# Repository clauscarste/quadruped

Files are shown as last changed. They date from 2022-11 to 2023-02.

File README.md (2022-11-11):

# high performance quadruped with fully actuated spine and brushless motors 
Project is part of my bachelor's thesis at the technical university Munich

Repostory inclues: 
- code running on raspbery pi (python3)
  - matlab scripts used to help create python code
- configuration of Odrive 
- STL files o 3D print and CNC/Laser cut 
- schematics for electronics 
overview_real
(white = FDM:PETG, Black = FDM:nylon-carbonfiber and Pulley Belt, Red = Aluminium 3mm, Blue = Fasteners, Orange = Siliconerubber)

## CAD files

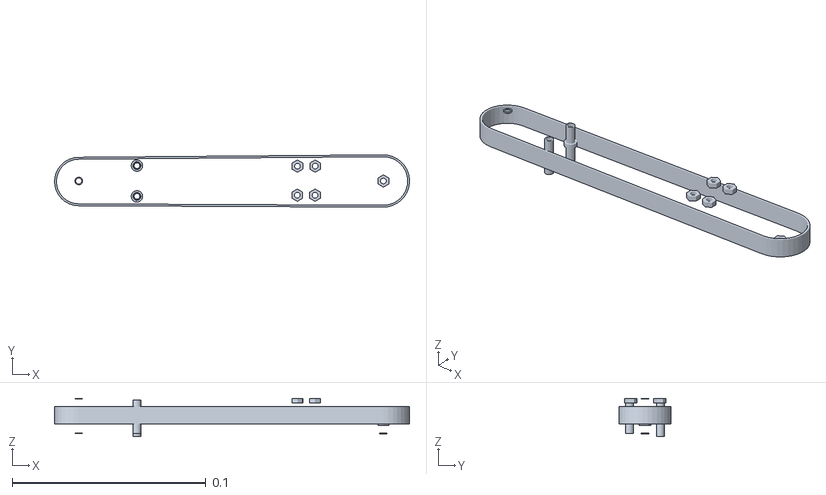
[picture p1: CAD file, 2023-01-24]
control and simulation/simulation_files/simulation_test/full_quadruped_simulation_pos_control/meshes/upper_leg_belt8.stl
0.183 x 0.027 x 0.0197

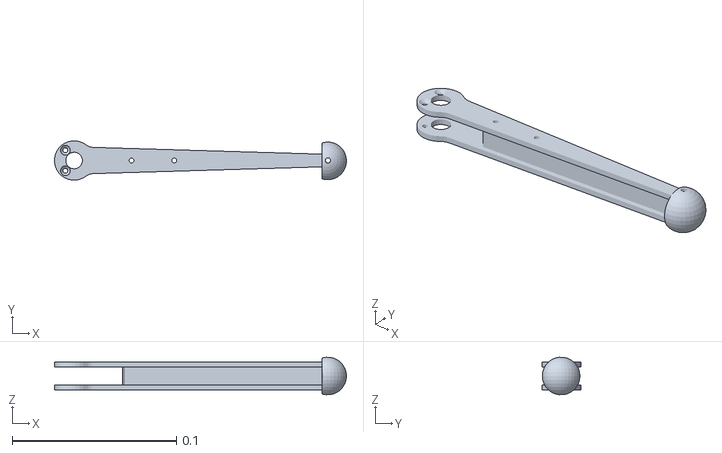
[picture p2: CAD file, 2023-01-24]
control and simulation/simulation_files/simulation_test/leg_only_simplided copy/meshes2/lower_leg7.stl
0.178 x 0.0239 x 0.0229

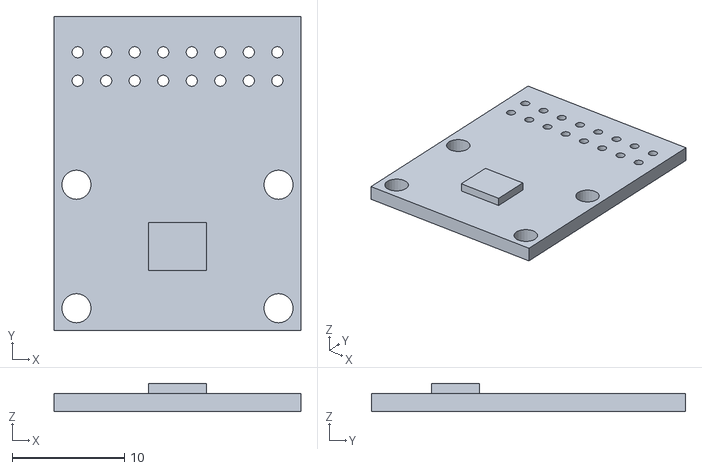
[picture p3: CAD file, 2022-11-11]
stl_files/Gearbox/g10.stl
22.0 x 28.0 x 2.51

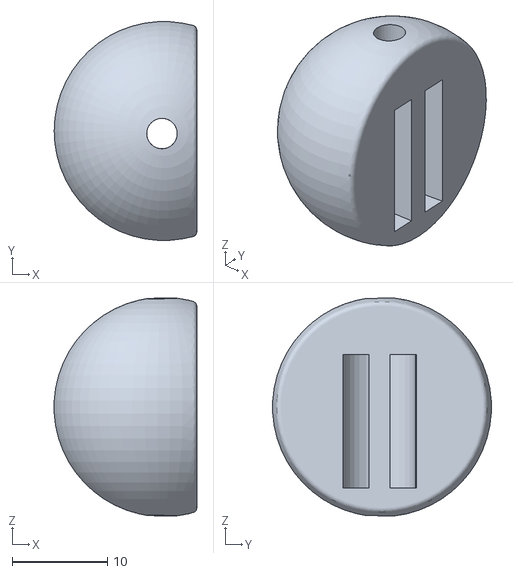
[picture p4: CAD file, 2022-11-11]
stl_files/Leg/l11.stl
15.0 x 22.9 x 22.9

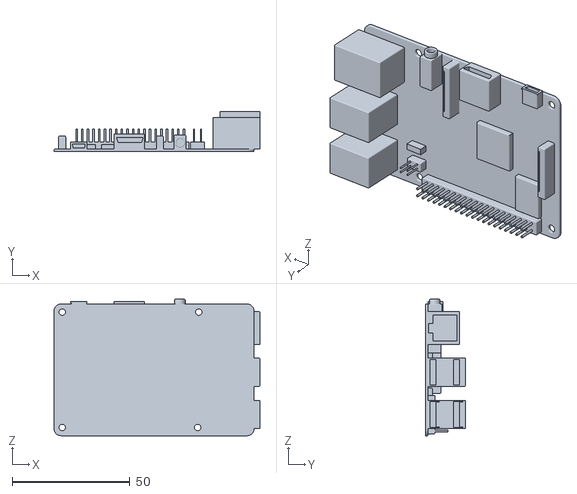
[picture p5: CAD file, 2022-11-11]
stl_files/Main Body/m14.stl
87.5 x 17.0 x 58.0

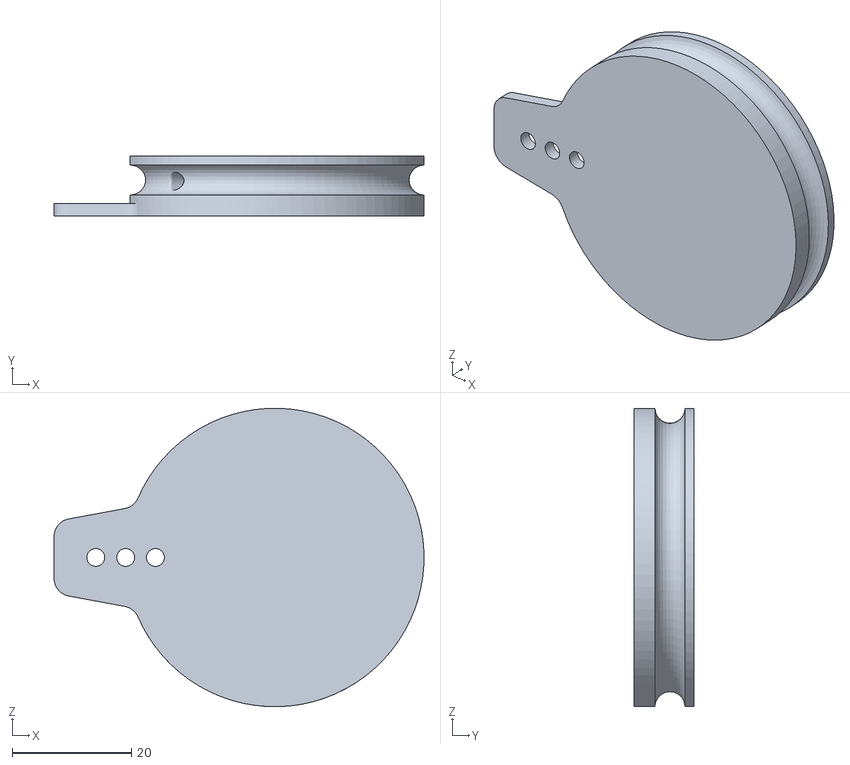
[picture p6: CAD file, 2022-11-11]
stl_files/Spine/s3.stl
62.0 x 10.0 x 50.0

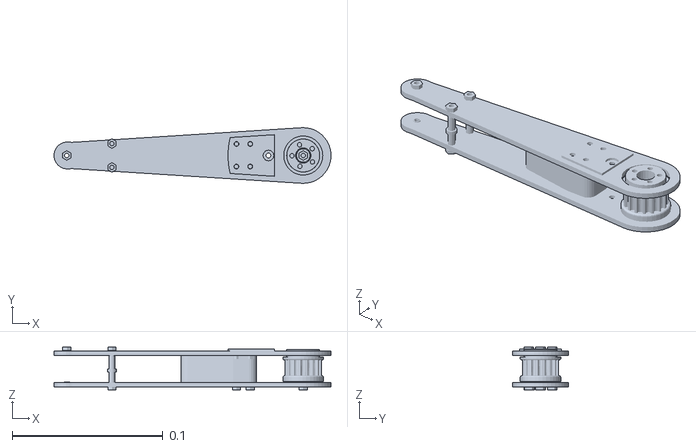
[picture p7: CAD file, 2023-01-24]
control and simulation/simulation_files/simulation_test/full_quadruped_simulation_pos_control/meshes/upper_leg8.stl
0.184 x 0.0369 x 0.0285

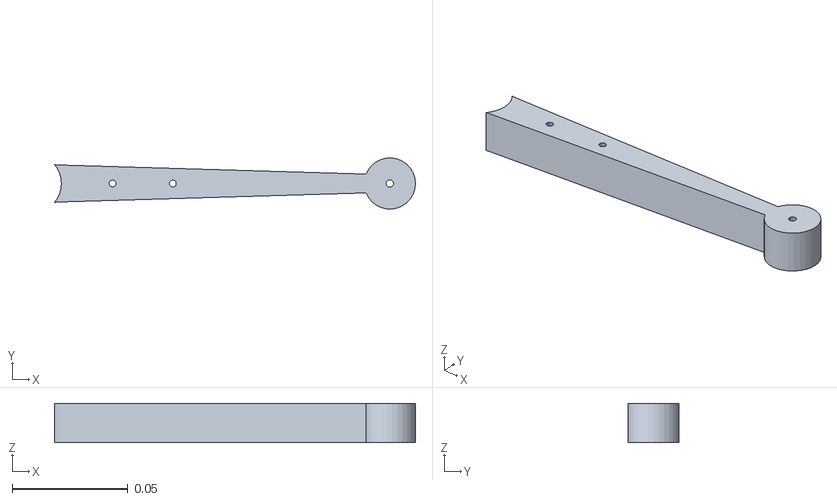
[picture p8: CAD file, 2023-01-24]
control and simulation/simulation_files/simulation_test/leg_only_simplided copy/meshes2/lower_leg.stl
0.156 x 0.0221 x 0.017

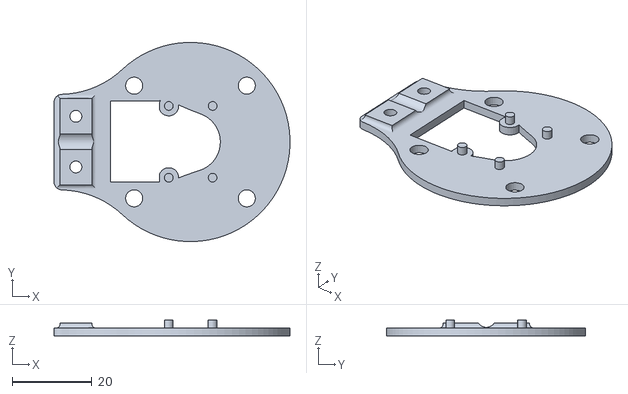
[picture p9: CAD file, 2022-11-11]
stl_files/Gearbox/g11.stl
59.2 x 50.0 x 4.00

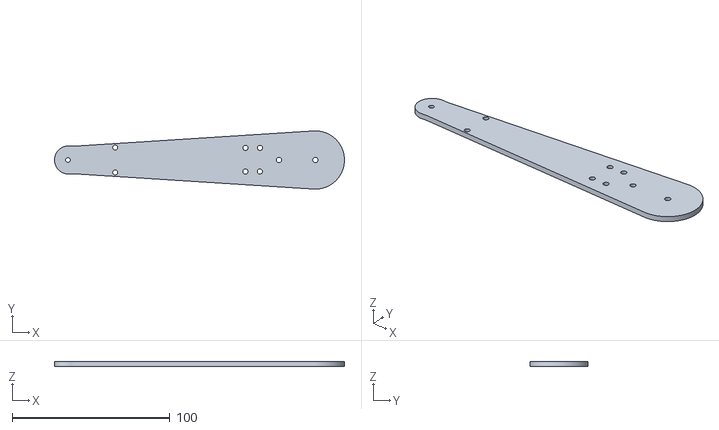
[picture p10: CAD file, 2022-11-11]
stl_files/Leg/l4.stl
184.1 x 37.0 x 3.00

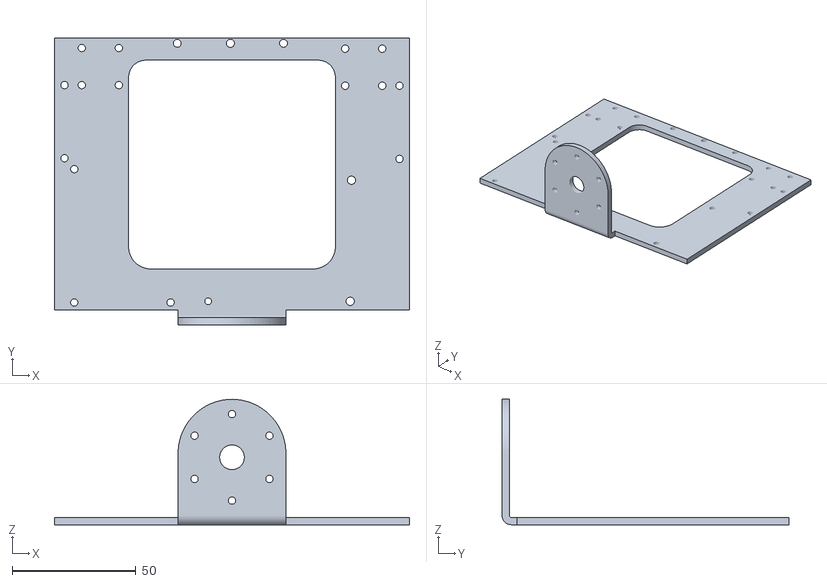
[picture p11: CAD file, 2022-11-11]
stl_files/Main Body/m4.stl
143.7 x 116.2 x 50.8

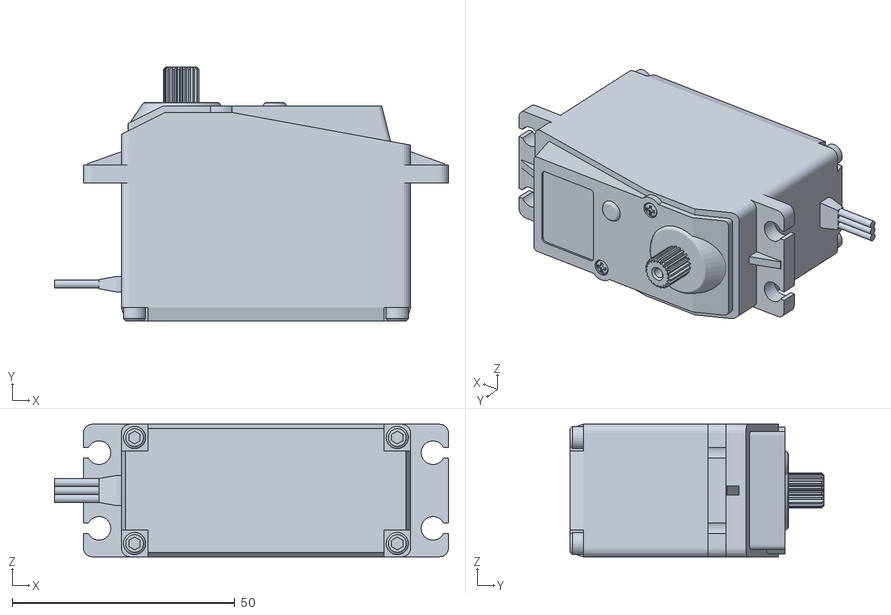
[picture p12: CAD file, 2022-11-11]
stl_files/Spine/s5.stl
88.5 x 57.0 x 29.8

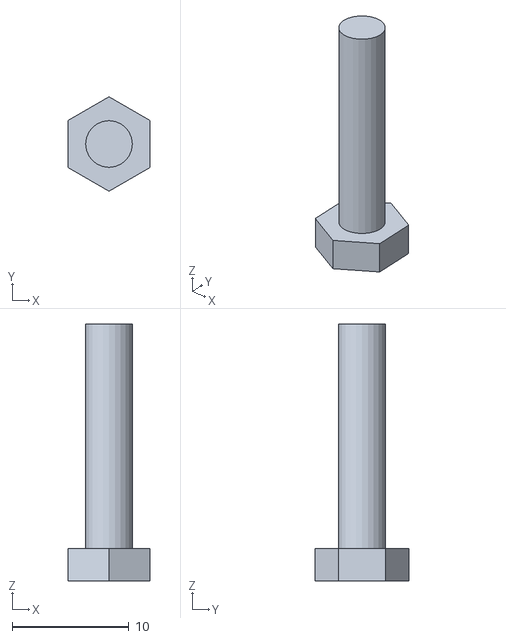
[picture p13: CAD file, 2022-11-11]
stl_files/Gearbox/g9.stl
7.00 x 8.08 x 22.0

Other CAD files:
control and simulation/simulation_files/full_quadruped_simulation_servo/meshes/back_alu_1.stl
control and simulation/simulation_files/full_quadruped_simulation_servo/meshes/back_alu_2.stl
control and simulation/simulation_files/full_quadruped_simulation_servo/meshes/battery.stl
control and simulation/simulation_files/full_quadruped_simulation_servo/meshes/encoder.stl
control and simulation/simulation_files/full_quadruped_simulation_servo/meshes/front_alu_1.stl
control and simulation/simulation_files/full_quadruped_simulation_servo/meshes/front_alu_3.stl
control and simulation/simulation_files/full_quadruped_simulation_servo/meshes/gearbox1_spacer.stl
control and simulation/simulation_files/full_quadruped_simulation_servo/meshes/spacer_spine.stl
control and simulation/simulation_files/full_quadruped_simulation_servo/meshes/upper_leg.stl
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

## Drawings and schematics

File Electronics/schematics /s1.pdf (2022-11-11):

## PWMServo Driver PCA9685

## V+ 16 VCC 17 SDA 18 SCL 19 OE 20 GND 21

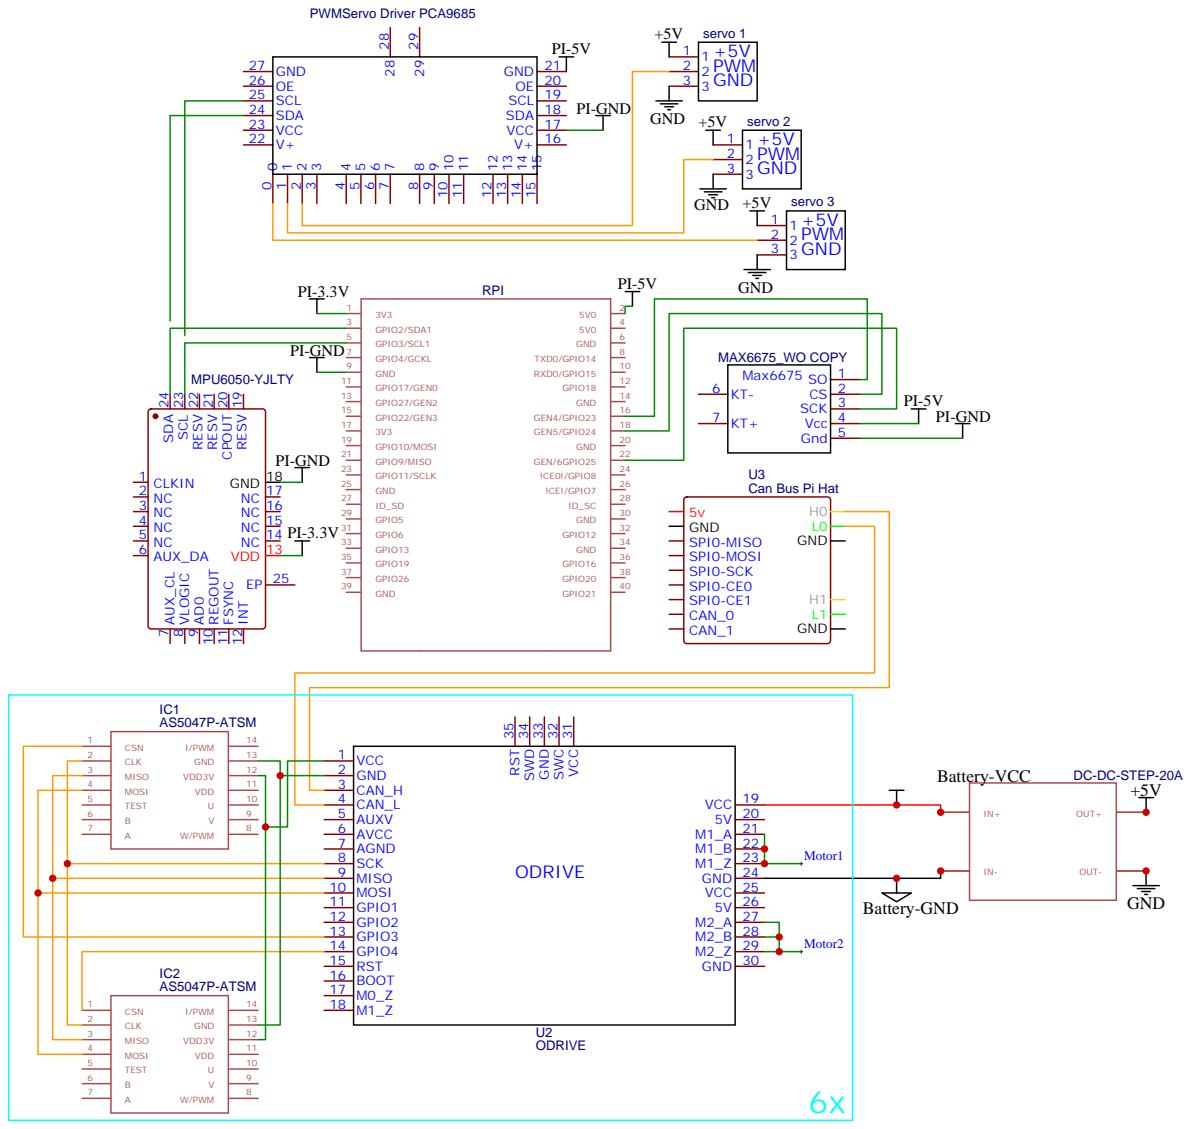
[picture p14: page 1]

V+ 22 VCC 23 SDA 24 SCL 25 OE 26 GND 27

VDD 13 NC 14 NC 15 NC 16 NC 17 GND 18 RESV 19 CPOUT 20

Can Bus Pi Hat

ODRIVEVCC 31 SWC 32 GND ³³ SWD ³⁴ RST 35

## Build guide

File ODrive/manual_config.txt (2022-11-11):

**Configuring the Odrives is best done on a PC running Linux (Ubuntu) using a USB cable that has a ferrite ring to ensure good conection. Blocks of commands can be all sent together. After each block it is advised to restart the Odrive. **

**Config:**
***step 1 run all the commands below in the Odrivetool***

odrv0.config.dc_bus_undervoltage_trip_level = 15
odrv0.config.dc_bus_overvoltage_trip_level = 21.2
odrv0.config.dc_max_positive_current = 140
odrv0.config.dc_max_negative_current = -12
odrv0.axis0.motor.config.current_lim = 50
odrv0.axis0.motor.config.motor_type = 0
odrv0.axis0.motor.config.pole_pairs = 20
odrv0.axis0.motor.config.torque_constant = 8.27 / 130
odrv0.axis0.encoder.config.abs_spi_cs_gpio_pin = ********must be set to 7 or 8***********
odrv0.axis0.encoder.config.mode = ENCODER_MODE_SPI_ABS_AMS
odrv0.axis0.encoder.config.cpr = 2**14
odrv0.axis0.controller.config.pos_gain = 50
odrv0.axis0.controller.config.vel_gain = 0.5
odrv0.axis0.controller.config.vel_integrator_gain = 0.0
odrv0.axis0.config.can_node_id = ********must be set according to the defined axis naming***********
odrv0.axis0.controller.config.vel_limit = 20
odrv0.axis0.config.can_heartbeat_rate_ms = 500
odrv0.save_configuration()

***step 2: Initial motor inductance and encoder offset calibration. Run all the commands below - the motor should spin in two directions slowly by half a rotation***

odrv0.axis0.requested_state = AXIS_STATE_FULL_CALIBRATION_SEQUENCE
odrv0.axis0.motor.config.pre_calibrated = True
odrv0.axis0.encoder.config.pre_calibrated = True
odrv0.save_configuration()

***step 3: Filter - Run all commands belwo***
odrv0.axis0.controller.config.input_mode = INPUT_MODE_POS_FILTER
odrv0.axis0.controller.config.input_filter_bandwidth = 20
odrv0.save_configuration()

**Helpful commands for testing: and debugging**
**Debug:**
dump_errors(odrv0)
odrv0.clear_errors()
odrv0..axis0.clear_errors()
odrv0.vbus_voltage
odrv0.axis0.motor.current_control.Iq_measured
odrv0.save_configuration()

**Testing movement**
odrv0.axis0.motor.config.current_lim = 1
odrv0.axis0.requested_state = AXIS_STATE_CLOSED_LOOP_CONTROL
odrv0.axis0.controller.input_pos = 1
odrv0.axis0.requested_state = AXIS_STATE_IDLE

***run all commands from above again but replace axis0 with axis1***

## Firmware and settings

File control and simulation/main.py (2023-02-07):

#general imports
from __future__ import division
import time
import numpy as np
import kinematics_legs
import walking
#import kinematics_spine                #not implemented in simulation and not used in real word currently
import jumping

import datetime as dt
import matplotlib.pyplot as plt
import matplotlib.animation as animation

#############################  uncomment real world and simulation here and in the kinematics_legs.py  ################
#for real world testing
"""
from realworld import temprature_readout
from realworld import can_comunication
can_comunication.dictionary()
"""
#for simulation
from simulation import temprature_readout
from simulation import can_comunication

#############################  uncomment real world and simulation here and in the kinematics_legs.py  ################


# Config File Import
import configparser
#Config file reading is done in main loop

def get_measured_force():
    return can_comunication.measured_force

def main_loop():
    #config file reading
    config_obj = configparser.ConfigParser()
    config_obj.read("/Users/claus/pyc/quadruped/control and simulation/configfile.ini")

    save_operation_limits = config_obj["save_operation_limits"]
    servo_config = config_obj["servo_config"]
    motor_config = config_obj["motor_config"]
    can_retry_amount = config_obj["can_retry_amount"]

    # Temprature and Voltage limits of motors and battery
    save_operation = True
    temprature_limit = float(save_operation_limits["temprature_limit"])
    battery_voltage_lower_limit = float(save_operation_limits["battery_voltage_lower_limit"])
    battery_voltage_upper_limit = float(save_operation_limits["battery_voltage_upper_limit"])

    # servo_initial_angles and ofset (negative defined)
    servo_1_inital_angle = float(servo_config["servo_1_inital_angle"])
    servo_2_inital_angle = float(servo_config["servo_2_inital_angle"])
    servo_3_inital_angle = float(servo_config["servo_3_inital_angle"])
    servo_ofset = list(map(float, (servo_config["servo_ofset"]).split()))
    distance_center_of_spine_to_rope_m = float(servo_config["distance_center_of_spine_to_rope_m"])
    spine_length = float(servo_config["spine_length"])
    max_angle = float(servo_config["max_angle"])
    pully_radius = float(servo_config["pully_radius"])
    norma_rope_length = float(servo_config["norma_rope_length"])

    # Motor parameters
    motor_inital_x = list(map(float, (motor_config["motor_inital_x"]).split()))
    motor_inital_y = list(map(float, (motor_config["motor_inital_y"]).split()))
    motor_inital_z = list(map(float, (motor_config["motor_inital_z"]).split()))
    ofset = list(map(float, (motor_config["ofset"]).split()))
    limit = list(map(float, (motor_config["limit"]).split()))
    invert_axis = (list(map(int, (motor_config["invert_axis"]).split())))
    leg_parameters = list(map(float, (motor_config["leg_parameters"]).split()))
    can_comunication.kpkv = list(map(float, (motor_config["kpkv"]).split()))
    robot_length = float(motor_config["robot_length"])
    robot_with = float(motor_config["robot_with"])
    contact_f = float(motor_config["contact_f"])

    leg_config = float(motor_config["leg_config"])
    step_lentgh = float(motor_config["step_lentgh"])
    stance_max_height = float(motor_config["stance_max_height"])
    flight_max_heigth = float(motor_config["flight_max_heigth"])
    neutral_height = float(motor_config["neutral_height"])
    speed_stance = int(motor_config["speed_stance"])
    speed_flight = int(motor_config["speed_flight"])
    acceleration_stance = float(motor_config["acceleration_stance"])
    deceleration_stance = float(motor_config["deceleration_stance"])
    acceleration_flight = float(motor_config["acceleration_flight"])
    deceleration_flight = float(motor_config["deceleration_flight"])

    # Number of times to retry after failing to send message over can bus
    closed_loop_attempt = int(can_retry_amount["closed_loop_attempt"])
    ### # end of config file reading


    #fixed values for now
    xm = 0
    ym = 0
    zm = 0
    yaw = 0
    pich= 0
    roll= 0

    #### Inital steps after startup####
    # Spine setup to zero position
    #kinematics_spine.inverse_kinematics_spine(0,0,distance_center_of_spine_to_rope_m,servo_ofset,max_angle,spine_length,pully_radius,norma_rope_length)

    # test that can works and encoders give good reading - also fill in libary
    for i in [0, 1, 2, 3, 4, 5, 6, 7, 8, 9, 10, 11,0, 1, 2, 3, 4, 5, 6, 7, 8, 9, 10, 11]:
        can_comunication.get_encoder_estimate(i)
    for i in [0, 1, 2, 3, 4, 5, 6, 7, 8, 9, 10, 11]:
        print(can_comunication.get_encoder_estimate(i), "     this is ", i)

    # set motor closed loop
    can_comunication.setall_closed(closed_loop_attempt)

    #Set motor to inital positon
    upper = -0.25
    land = -0.25
    lower = -0.25
    delay = 0.1
    jumping.jump(land, upper, lower, delay, leg_parameters, ofset, limit, invert_axis, leg_config, yaw, pich, roll, xm,
                 ym, zm, robot_length, robot_with)

    ###### Main loop based on keyboard input ######
    while save_operation == True:
         # chck for save operation (temprature and battery voltage)
        if can_comunication.is_bus_voltage_in_limit(battery_voltage_lower_limit,battery_voltage_upper_limit) is False or temprature_readout.is_temp_in_limit(temprature_limit) is False:
            save_operation = False
            can_comunication.setall_idle()
            print("not save")
        ##temporary override to always start walking
        #can_comunication.currently_walking = True
        if can_comunication.walk == True and can_comunication.currently_walking == False:
            can_comunication.currently_walking = True
            can_comunication.walk = False
        if can_comunication.walk == True and can_comunication.currently_walking:
            can_comunication.currently_walking = False
            can_comunication.walk = False
        if can_comunication.jump == True:
            can_comunication.jump = False
            upper = -0.15
            land = -0.25
            lower = -0.25
            delay = 4
            jumping.jump(land, upper, lower, delay, leg_parameters, ofset, limit, invert_axis, leg_config, yaw, pich,
                         roll, xm, ym, zm, robot_length, robot_with)
        if can_comunication.lower == True:
            can_comunication.lower = False
            #jumping.jump() #to be impemented
        if can_comunication.set_all_motors_idle == True:
            can_comunication.set_all_motors_idle = False
            can_comunication.setall_idle()
        if can_comunication.set_all_motors_closed_loop == True:
            can_comunication.set_all_motors_closed_loop = False
            can_comunication.setall_closed(closed_loop_attempt)
        if can_comunication.increase_speed == True:
            can_comunication.increase_speed = False
            sepped_balance = sepped_balance + 1
        if can_comunication.decrease_speed == True:
            can_comunication.decrease_speed = False
            sepped_balance = sepped_balance - 1
        if can_comunication.incease_left == True:
            can_comunication.incease_left = False
            left_right_balance = left_right_balance - 1
        if can_comunication.incease_right == True:
            can_comunication.incease_right = False
            left_right_balance = left_right_balance + 1
        ## implement speed and direction ### with left_right_balance and sepped_balance

        if can_comunication.currently_walking == True:
            #walking.one_step_at_a_time(step_lentgh, stance_max_height, flight_max_heigth, neutral_height, speed_stance,
            #                   acceleration_stance, deceleration_stance, speed_flight, acceleration_flight,
            #                   deceleration_flight,
            #                   yaw, pich, roll, xm, ym, zm, robot_length, robot_with, leg_parameters, ofset, limit,
            #                   invert_axis, leg_config)

            walking.walking_sequence(step_lentgh, stance_max_height, flight_max_heigth, neutral_height, speed_stance,
                                      acceleration_stance, deceleration_stance, speed_flight, acceleration_flight,
                                      deceleration_flight,
                                      yaw, pich, roll, xm, ym, zm, robot_length, robot_with, leg_parameters, ofset, limit,
                                      invert_axis, leg_config)
                

        else:
            upper = -0.25
            land = -0.25
            lower = -0.25
            delay = 0.1
            jumping.jump(land,upper,lower,delay,leg_parameters, ofset, limit, invert_axis, leg_config, yaw, pich, roll, xm, ym, zm, robot_length, robot_with)


    ##Testing other fuctionality

    #setting closed and idle
    #can_comunication.set_closed_loop(3,2)
    #can_comunication.set_closed_loop(4,2)
    #can_comunication.set_closed_loop(5,2)
    #can_comunication.setall_idle()
    #can_comunication.setall_closed(5)

    #Plot walking curve
    #walking.ploting(walking.curve_stance(1,step_lentgh,stance_max_height,neutral_height,speed_stance,acceleration_stance,deceleration_stance))
    #walking.ploting(walking.curve_flight(1,step_lentgh,flight_max_heigth,neutral_height,speed_flight,acceleration_flight,deceleration_flight))

    #test inverse kinematics
    #print(kinematics_legs.yaw_pich_roll(yaw, pich, roll, xm, ym, zm, robot_length,robot_with, leg_id, x, y, z))

    #Test force response
    #for i in np.arange(-0.15, -0.299, -0.001):
    #    time.sleep(0.001)
    #    kinematics_legs.inverse_kinematics_legs(0, 0, i, 0.1, leg_parameters, ofset, limit, invert_axis, leg_config, yaw, pich, roll, xm,
    #                            ym, zm, robot_length,robot_with)

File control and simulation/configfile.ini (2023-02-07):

#Temprature and Voltage limits of motors and battery
[save_operation_limits]
temprature_limit = 70
battery_voltage_lower_limit = 15
battery_voltage_upper_limit = 22


#servo_initial_angles and ofset (negative defined)
[servo_config]
servo_1_inital_angle = 0
servo_2_inital_angle = 0
servo_3_inital_angle = 0
servo_ofset = -0 -0 -0
distance_center_of_spine_to_rope_m = 0.07
spine_length = 0.13
max_angle = 20
pully_radius = 0.23
norma_rope_length = 0.13

#Motor parameters
[motor_config]
#motor inital angels after startup
motor_inital_x = 0 0 0 0
#motor_inital_y = -0.25 -0.25 -0.25 -0.25
motor_inital_y = -0.2999 -0.2999 -0.2999 -0.2999
motor_inital_z = 0.1 0.1 0.1 0.1
#ofset of each motor +calculated by helper function to have zero degree position at a the same point for every motor regardless of the instalation orientation of the encoder
ofset = 15.8 -40.56 30 -25.2 -20.6 -1.2 20.3 20.9 -3 6 34 -12.4
#limit of each motor seen from the set zero degree position +calculated by helper function
limit = 300 300 300 300 300 300 300 300 300 300 300 300
#inversion of each motor to achive desired positve defined movement direction
invert_axis = 0 1 1 1 1 1 0 0 0 1 0 0
#length of joints pivot, hip, knee
leg_parameters = 0.1 0.15 0.15
kpkv = 38 0.4
#length and with of robot
robot_length = 0.4
robot_with = 0.2
#force in N to detect contact with the floor
contact_f = 1
#0 for legs crossed and 1 for front and back legs to be the same
leg_config = 0


step_lentgh = 0.13
stance_max_height = 0.02
flight_max_heigth = 0.07
neutral_height = 0.22
speed_stance = 200
speed_flight = 200
acceleration_stance = 0.01
deceleration_stance = 0.01
acceleration_flight = 0.01
deceleration_flight = 0.01


#Number of times to retry after failing to send message over can bus
[can_retry_amount]
closed_loop_attempt = 2

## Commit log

2022-05-24 first tests with CAN comunication, servo controll, temprature readout and some kinematics
2022-06-09 adding config for Odirve and some small changes to servo.py, kinematics and the can comunication fixing issues seen after doing testing
    [can_comunication.py, kinematics_legs.py, servo.py]
2022-06-15 solved problems with can bus and added mpu and first walking code
    [MPU_interface.py, can_comunication.py, kinematics_legs.py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]
2022-06-16 - added automatic retry if can comunication fails - changes to kinematics - added all variables in config section in main - changed the baud rate of the Odrive in the manual config txt
    [can_comunication.py, kinematics_legs.py, main.py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]
2022-06-21 added way to measure the speed of the CAN bus. And added can function to get the currently used current to then calculate the force from that.
2022-06-22 added way to set current limit. And small changes to can speed testing.
2022-06-24 added walking.py that is based on alterin a sin curve and sending that to the kinematics.py. Also some imporvements to force measurement were made.
2022-06-24 fixed kinematics and walking after real world testing
    [kinematics_legs.py, walking.py]
2022-06-25 changes can to use a seperate thread
2022-06-25 fixed thread problems after real world testing
    [can_comunication.py, can_thread.py]
2022-08-06 added spine inverse kinematics, totaly changed the servo interface. And added some varaibels to the config and the main that are important for the spine inverse kinematics. Also samll changes to can 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
    [can_comunication.py, configfile.ini, kinematics_spine.py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]
2022-08-17 small fix to corect for cordinate frame orientation
    [kinematics_legs.py, walking.py]
2022-08-17 add yaw pich and ajustments for cordinate frames.
2022-08-17 add yaw pich and ajustments for cordinate frames. Also added matlab files
2022-11-24 made changes to current control to make testing for simulation possible - main now only outputs angles from walking and there is no need for any inputs
2022-11-24 adding intrface from current control to simulation
2022-11-25 adding all features that the can comunication.py and the can thread.py have to the siminterface.py
